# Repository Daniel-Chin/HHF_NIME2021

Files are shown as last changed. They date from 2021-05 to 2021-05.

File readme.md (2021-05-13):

# Hyper-hybrid flute, for NIME 2021
This is a snapshot of the HHF repository taken for NIME 2021. The main repository is at https://github.com/Daniel-Chin/HHF.  

- It does not incorporate the regression results, so everything is still linear;  
- and, there is a live camera capture feature for demo recording.  

This readme presents a short tutorial on how to run the demo on your computer. 

## Contact me
If it is confusing, please send feedback to me or open an issue. If you need further assistance, feel free to contact me via email.  

## How to run
### Download Processing 3
You need Processing 3 to run the software interface.  
Official site: https://processing.org/  
Download page: https://processing.org/download/  

(For those who do not want to install anything: on Windows, Processing 3 is a standalone exe.)  

Then, use Processing 3 to open file `./proc/proc.pde`. Press the play button to run.  

### Connect a MIDI output
The demo outputs MIDI messages. To hear sounds, you need to connect the demo with either a software synthesizer or a physical synthesizer.  

If you do not have any synthesizers available, Windows comes with a "Microsoft GS Wavetable Synth" that also works.  

To configure the MIDI output, edit `./midi.pde`. In that file, search for `myBus = new MidiBus`. Change the device name to your device. To see a list of detected MIDI devices, run the Processing sketch and take a look at the log output. The log output is below the source code editor.  

## Parameters
Program parameters can be found at the top of `proc.pde` and `network.pde`.  

### Keyboard-and-mouse / touchscreen demo
If you want to run the keyboard-and-mouse demo, simply make sure that `DEBUGGING_NO_ARDUINO` is set to `true` on the top of `proc.pde`.  

An arguably better experience is achieved on a touchscreen. To use the touchscreen mode, make sure that `TOUCH_SCREEN` is set to `true` on the top of `proc.pde`.  

### With-hardware demo
If you want to run the demo with our hardware, make sure that `DEBUGGING_NO_ARDUINO` is set to `false` on the top of `proc.pde`.  

Then, refer to the next section, "Hardware fabrication". 

Then, you need to setup the Bluetooth connection as a Serial port on your OS. You may refer to tutorials on "HC05 with Arduino".  

To configure the HC-05 Bluetooth module, use our helper sketch at `./ardu/setupBluetooth/setupBluetooth.ino`. 

Finally, upload `./ardu/ardu.ino` to the Arduino. 

## Hardware fabrication
### You will need
- 3D printing. 
- A six-hole recorder. 
- An Arduino Nano. 
- An HC05/HC06 Bluetooth module. 
- A BMP085 sensor. 
- Some moisture absorbers. (We just took some from packaged food.)
- A 5V battery. 
- Some bronze tape. 
- Jumper cables. 
- Optionally, 3mm-diameter nuts and bolts. 

### General guidelines
- Put bronze tape onto the recorder holes as capacitive sensors. Connect them to Arduino pin 7, 6, 5, 4, 3, 2. 
- Bluetooth Serial pins to Arduino pin 10 for RX, 11 for TX. Notice that you may need to drop the voltage to 3.3V in order to not overload the HC05. However, there is a Chinese HC06 variant that officially supports 5V. 
- Make the sensorBox. 3D models are at `./3d_models/`. I recommend to *only add support that touches buildplate*. A 3mm nut and bolt can be used to secure the sensor in the sensorBox. Add moisture absorbers above the grates. Seal the sensorBox air-tight with tape. `boxRing.stl` and `ringRail.stl` are optional parts that secure the sensorBox in the mouthpiece.  
- Connect the sensorBox sensor data pins to SDA and SCL on your Arduino.  
- Use the battery to power the Arduino.  

Again, if you have questions about any of the above steps, please refer to the "contact me" section above.

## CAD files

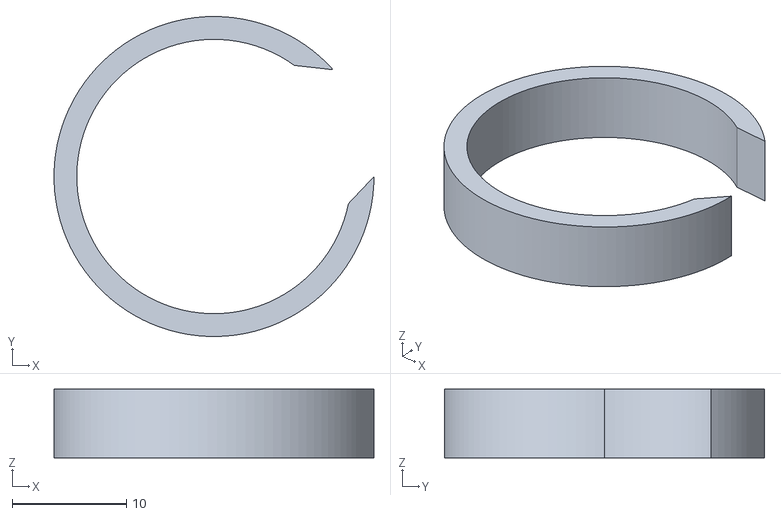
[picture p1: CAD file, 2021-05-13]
3d_models/boxRing.stl
28.0 x 28.0 x 6.00

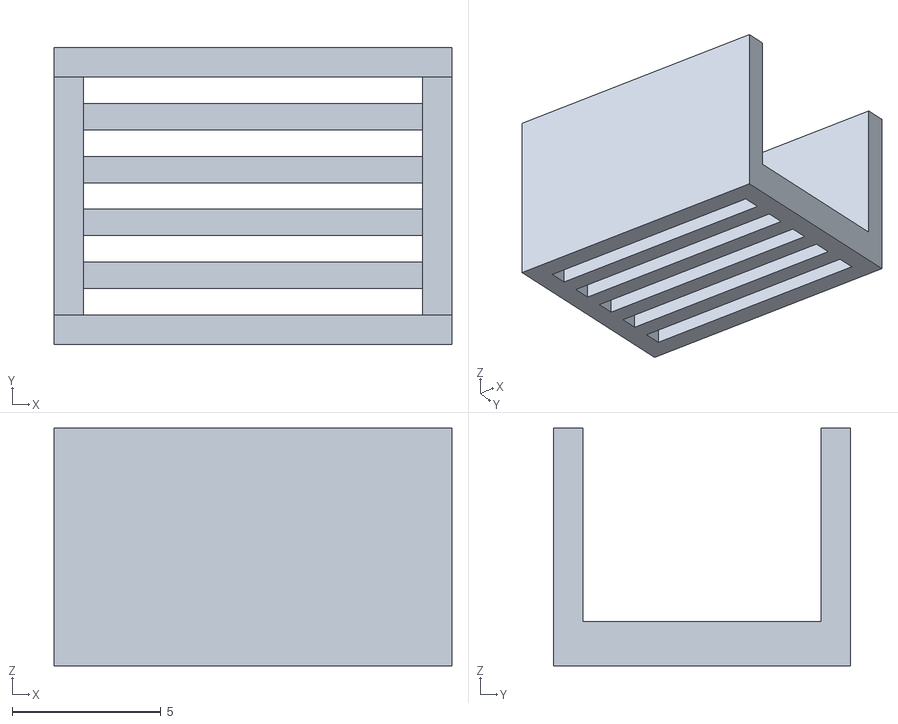
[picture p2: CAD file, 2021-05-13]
3d_models/airSensorBox_grate.stl
13.4 x 10.00 x 8.00

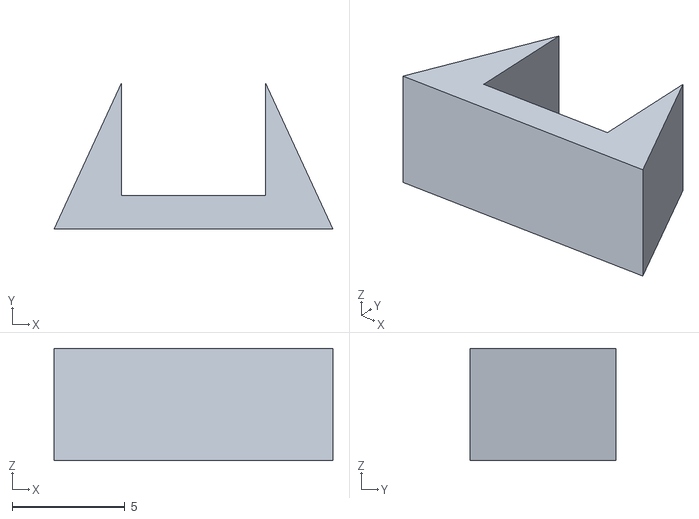
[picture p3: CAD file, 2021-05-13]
3d_models/ringRail.stl
12.4 x 6.50 x 5.00

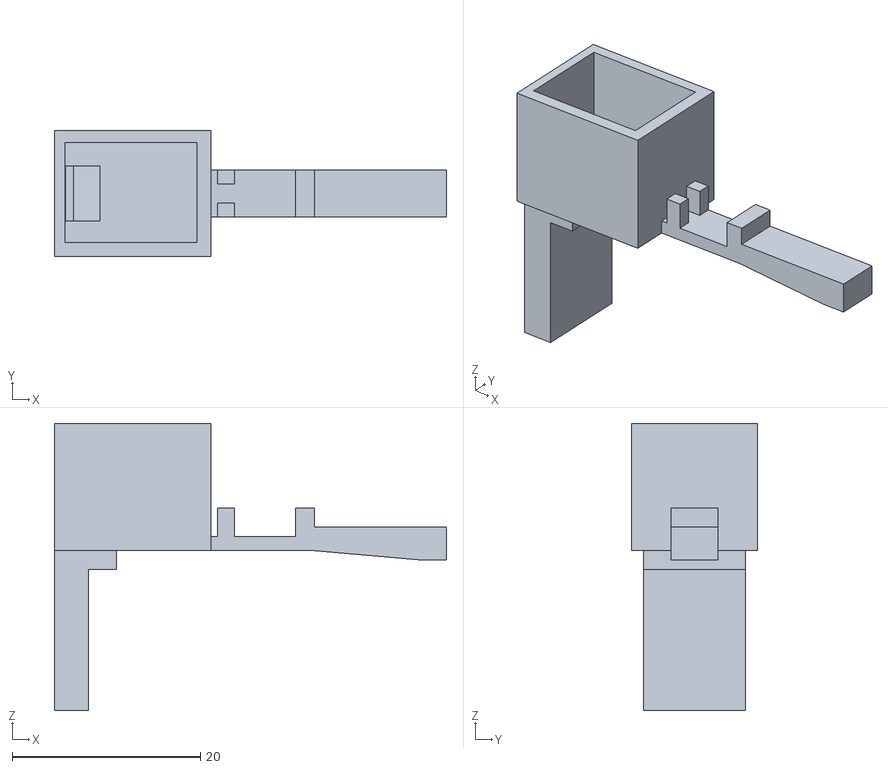
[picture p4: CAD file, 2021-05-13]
3d_models/airSensorBox_muter.stl
41.6 x 13.4 x 30.5

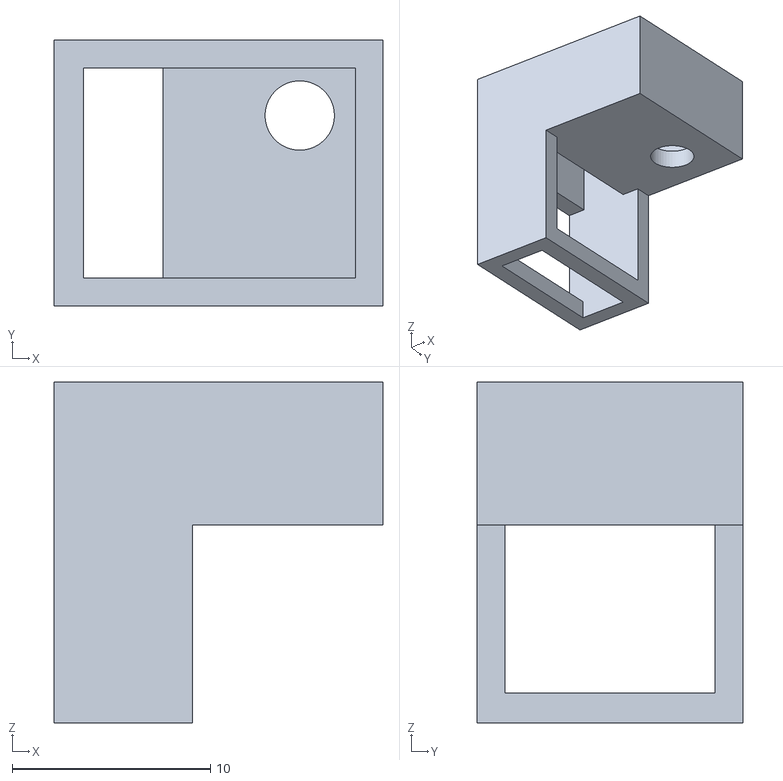
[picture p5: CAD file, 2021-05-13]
3d_models/airSensorBox_adaptor.stl
16.6 x 13.4 x 17.2

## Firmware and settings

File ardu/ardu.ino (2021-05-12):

#include <Wire.h>
#include <Adafruit_PWMServoDriver.h>
#include <SoftwareSerial.h>
#include <Adafruit_BMP085.h>

#define N_SERVOS 6
const int SERVO_PINS[N_SERVOS] = {10,11,12,13,14,15};
const int CAPACITIVE_PINS[N_SERVOS] = {7,6,5,4,3,2};
#define PEDAL_PIN 12
#define INIT_MID 95
#define DEFAULT_CAPACITIVE_THRESHOLD 2

#define MINPULSE 150 // This is the 'minimum' pulse length count (out of 4096)
#define MAXPULSE 600 // This is the 'maximum' pulse length count (out of 4096)
#define SERVO_FREQ 50 // Analog servos run at ~50 Hz updates
#define OSC_FREQ 24890000 // Specific to each PCA 9685 board

#define ROUND_ROBIN_PACKET_MAX_SIZE 127 // one-byte length indicator maximum 127 on serial

Adafruit_PWMServoDriver pwm;
Adafruit_BMP085 bmp;
SoftwareSerial blueSerial(10, 11); // RX, TX
bool _abort = false;

// For detach
int detach_slow = 5;
int last_degree[N_SERVOS] = {0};
int detach_target_degree[N_SERVOS] = {0};
int last_detach_millis;
int capacitive_threshold = DEFAULT_CAPACITIVE_THRESHOLD;
#define ATMOS_OFFSET 36000
int atmos_pressure = -1;
int measure_atmos_state = 20;
long measure_atmos_tmp = 0;
int measure_atmos_times = 0;

// For Serial communication
#define BUFF_LEN_S 4
#define BUFF_LEN_D 5
#define BUFF_LEN_C 1
#define BUFF_LEN_R 6
#define LONGEST_COMMAND 6  // max(BUFF_LEN_ S D R)
char command_buffer[LONGEST_COMMAND] = {' '};
char header = NULL;
int n_char_expect;
int n_char_got;
bool hand_shaked = false;

// For capacitive diffing
bool last_capacitive[N_SERVOS] = {false};

// For pedal diffing
bool last_pedal = false;

void setup() {
  // pwm = Adafruit_PWMServoDriver()
  // pwm.begin();
  // pwm.setOscillatorFrequency(OSC_FREQ);
  // pwm.setPWMFreq(SERVO_FREQ);

  // for (int i = 0; i < N_SERVOS; i++) {
  //   setServo(i, INIT_MID);
  //   last_degree[i] = INIT_MID; // in case you relax() before sending any attach command
  // }

  // pinMode(PEDAL_PIN, INPUT);
  blueSerial.begin(9600);
  String expecting = "hi arduino";
  int len = expecting.length();
  for (int i = 0; i < len; i++) {
    if (readOne() != expecting[i]) {
      _abort = true;
      fatalError("Handshake failed! ");
      return;
    }
  }
  blueSerial.print("hi processing");
  hand_shaked = true;
  
  if (! bmp.begin()) {
    fatalError("Could not find a valid BMP085 sensor, check wiring!");
    return;
  }

  last_detach_millis = millis();
}

char readOne() {    // blocking
  int recved = -1;
  while (recved == -1) {
    recved = blueSerial.read();
  }
  return (char) recved;
}

int heart_beat_count = 0;
void heartBeat() { // for debug
    heart_beat_count ++;
    if (heart_beat_count == 10000) {
        roundRobin_println("HEARTBEAT");
    }
    if (heart_beat_count == 30000) {
        heart_beat_count = 0;
        roundRobin_println("  HEARTBEAT");
    }
}

void loop() {
  if (_abort) {
    roundRobin_loop();
    delay(1);
    return;
  }
  roundRobin_loop();
  // heartBeat();
  // handleDetach();
  if (roundRobin_available() > 0) {
    mySerialEvent();
  }
  relayCapacitive();
  // relayPedal();
  relayPressure();
}

void mySerialEvent() {
  if (! hand_shaked) return;
  char recved;
  while (roundRobin_available()) {
    recved = roundRobin_read();
    if (header == NULL) {
      header = recved;
      n_char_got = 0;
      if (header == '\r') {
        n_char_expect = BUFF_LEN_R;
      } else if (header == 'S') {
        n_char_expect = BUFF_LEN_S;
      } else if (header == 'D') {
        n_char_expect = BUFF_LEN_D;
      } else if (header == 'C') {
        n_char_expect = BUFF_LEN_C;
      } else {
        fatalError("Unknown header: chr(" + String(int(header)) + ')');
        return;
      }
    } else {
      command_buffer[n_char_got] = recved;
      n_char_got ++;
      if (n_char_got == n_char_expect) {
        handleCommand();
        header = NULL;
      }
    }
  }
}

void handleCommand() {
  if (header == '\r') {
    String str_command = String(command_buffer).substring(0, 6);  // Stupid \x00 problem
    if (str_command.equals("ABORT_")) {
      _abort = true;
      return;
    } else {
      fatalError("Unknown command starting with \\r: ");
      roundRobin_println(str_command);
      return;
    }
  } else if (header == 'S' || header == 'D') {
    int servo_ID = int(command_buffer[1]) - int('2');
    if (command_buffer[0] == 'R') {
      servo_ID += 3;
    }
    if (servo_ID >= N_SERVOS || servo_ID < 0) {
      fatalError("Invalid servo ID: ");
      roundRobin_write(command_buffer[0]);
      roundRobin_write(command_buffer[1]);
      return;
    }
    int degree = decodeDegree(command_buffer[2], command_buffer[3]);
    if (isDegreeIllegal(degree)) {
      return;
    }
    if (header == 'S') {
      attach(servo_ID, degree);
    } else if (header == 'D') {
      detach_slow = decodeDigit(command_buffer[4]);
      detach(servo_ID, degree);
    }
  } else if (header == 'C') {
    capacitive_threshold = (int) command_buffer[0];
  }
}

bool isDegreeIllegal(int degree) {
  if (degree > 180 || degree < 0) {
    fatalError("Invalid degree: ");
    roundRobin_println(String(degree));
    return true;
  }
  return false;
}

void fatalError(String msg) {
  delay(100); // avoid two-way serial collision
  roundRobin_println("ERRArduino fatal Error: " + msg);
  _abort = true;
}

int decodeDigit(char x) {
  return (int) x - (int) '0';
}

int decodeDegree(char a, char b) {
  return 127 * (int(a) - 1) + int(b) - 1;
}

void detach(int servo_ID, int degree) {
  detach_target_degree[servo_ID] = degree;
}

void attach(int servo_ID, int degree) {
  setServo(servo_ID, degree);
  last_degree[servo_ID] = degree;
  detach_target_degree[servo_ID] = NULL;
}

void handleDetach() {
  while ((millis() + 1000 - last_detach_millis) % 1000 >= detach_slow) {
    last_detach_millis += detach_slow;
    last_detach_millis %= 1000;
    for (int i = 0; i < N_SERVOS; i++) {
      if (detach_target_degree[i] != NULL) {
        if (detach_target_degree[i] > last_degree[i]) {
          last_degree[i] ++;
        } else {
          last_degree[i] --;
        }
        setServo(i, last_degree[i]);
        if (last_degree[i] == detach_target_degree[i]) {
          detach_target_degree[i] = NULL;
        }
      }
    }
  }
}

uint8_t readCapacitivePin(int pinToMeasure) {
  volatile uint8_t* port;
  volatile uint8_t* ddr;
  volatile uint8_t* pin;
  byte bitmask;
  port = portOutputRegister(digitalPinToPort(pinToMeasure));
  ddr = portModeRegister(digitalPinToPort(pinToMeasure));
  bitmask = digitalPinToBitMask(pinToMeasure);
  pin = portInputRegister(digitalPinToPort(pinToMeasure));
  *port &= ~(bitmask);
  *ddr  |= bitmask;
  delay(1);
  uint8_t SREG_old = SREG; //back up the AVR Status Register
  noInterrupts();
  *ddr &= ~(bitmask);
  *port |= bitmask;
  uint8_t cycles = 17;
  if (*pin & bitmask) {
    cycles =  0;
  } else if (*pin & bitmask) {
    cycles =  1;
  } else if (*pin & bitmask) {
    cycles =  2;
  } else if (*pin & bitmask) {
    cycles =  3;
  } else if (*pin & bitmask) {
    cycles =  4;
  } else if (*pin & bitmask) {
    cycles =  5;
  } else if (*pin & bitmask) {
    cycles =  6;
  } else if (*pin & bitmask) {
    cycles =  7;
  } else if (*pin & bitmask) {
    cycles =  8;
  } else if (*pin & bitmask) {
    cycles =  9;
  } else if (*pin & bitmask) {
    cycles = 10;
  } else if (*pin & bitmask) {
    cycles = 11;
  } else if (*pin & bitmask) {
    cycles = 12;
  } else if (*pin & bitmask) {
    cycles = 13;
  } else if (*pin & bitmask) {
    cycles = 14;
  } else if (*pin & bitmask) {
    cycles = 15;
  } else if (*pin & bitmask) {
    cycles = 16;
  }
  SREG = SREG_old;
  *port &= ~(bitmask);
  *ddr  |= bitmask;
  return cycles;
}

void relayCapacitive() {
  for (int i = 0; i < N_SERVOS; i ++) {
    uint8_t reading = readCapacitivePin(CAPACITIVE_PINS[i]);
    bool is_finger_down = reading >= capacitive_threshold;
    if (is_finger_down != last_capacitive[i]) {
      last_capacitive[i] = is_finger_down;
      roundRobin_write('F');
      roundRobin_write((char) ((int)'0' + i));
      if (is_finger_down) {
        roundRobin_write('_');
      } else {
        roundRobin_write('^');
      }
    }
  }
}

void relayPedal() {
  bool now_pedal = digitalRead(PEDAL_PIN);
  if (now_pedal != last_pedal) {
    last_pedal = now_pedal;
    roundRobin_write('P');
    if (now_pedal) {
      roundRobin_write('_');
    } else {
      roundRobin_write('^');
    }
    roundRobin_write(';');
  }
}

void setServo(int id, int angle) {
  pwm.setPWM(SERVO_PINS[id], 0, map(angle, 0, 180, MINPULSE, MAXPULSE));
}

void sendDebugMsg(String msg) {
  roundRobin_write('D');
  roundRobin_print(msg.substring(0, 2));
}

// Round Robin
String round_robin_in_queue = "";
String round_robin_out_queue = "";
int round_robin_my_turn = false;
int round_robin_recv_state = -1;

void roundRobin_loop() {
  if (round_robin_my_turn) {
    int packet_size = min(round_robin_out_queue.length(), ROUND_ROBIN_PACKET_MAX_SIZE);
    blueSerial.write((char) packet_size);
    if (packet_size > 0) {
      blueSerial.print(round_robin_out_queue.substring(0, packet_size));
      round_robin_out_queue = round_robin_out_queue.substring(packet_size);
    }
    round_robin_my_turn = false;
    round_robin_recv_state = -1;
  } else if (! _abort) {
    while (blueSerial.available() > 0) {
      if (round_robin_recv_state == -1) {
        round_robin_recv_state = blueSerial.read();
      } else {
        // rr_state > 0
        round_robin_in_queue += (char) blueSerial.read();
        // This leads to memory fragmentation quickly. 
        // Too bad.
        round_robin_recv_state -= 1;
      }
      if (round_robin_recv_state == 0) {
        round_robin_my_turn = true;
        break;
      }
    }
  }  
}

int roundRobin_available() {
  return round_robin_in_queue.length();
}

char roundRobin_read() {
  char tmp = round_robin_in_queue.charAt(0);
  round_robin_in_queue = round_robin_in_queue.substring(1);
  return tmp;
}

void roundRobin_write(char x) {
  round_robin_out_queue += x;
}

void roundRobin_print(String x) {
  round_robin_out_queue += x;
}

void roundRobin_println(String x) {
  roundRobin_print(x);
  roundRobin_write('\n');
}

void relayPressure() {
  int p = bmp.readPressure() - ATMOS_OFFSET;
  if (measure_atmos_state >= 0) {
    measure_atmos_tmp += p;
    measure_atmos_times ++;
    if (measure_atmos_state == 0) {
      atmos_pressure = measure_atmos_tmp / measure_atmos_times;
      // roundRobin_print("E");
      // roundRobin_print(String(atmos_pressure));
    }
    measure_atmos_state --;
  } else {
    p -= atmos_pressure;
    p = max(0, p);
    roundRobin_write('B');
    roundRobin_print(encodePrintable(p));
  }
}

String encodePrintable(int x) {
  int residual = x % 95;
  int high = (x - residual) / 95;
  high = min(94, high);
  char buffer[3] = { 0 };   // \x00 termination
  buffer[0] = (char)(high + 32);
  buffer[1] = (char)(residual + 32);
  String result = buffer;
  return result;
}

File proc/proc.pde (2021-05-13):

import java.util.Arrays;
import processing.serial.*;
import processing.video.*;

final static boolean DEBUGGING_NO_ARDUINO = true;
// true: a mouse-based demo. false: connects to the hardware. 
final static int COM = 3;
// Port ID. In console log, look for the bluetooth port. 
final static boolean TOUCH_SCREEN = false;
final static float FLUTE_BEND_MAX = .3;
// pitch bend coefficient. 
final static int CAPACITIVE_THRESHOLD = 3;
// increase on humid days. 
final static int LOW_PASS = 75;
// low pass filter, milliseconds. 
final static boolean MIDI_advanced_expression = false;
// whether MIDI channel 7 or 11 is used. 
final static int MAX_VELOCITY = 600;
// if using the mouse-based demo, the top of the screen corresponds to MAX_VELOCITY
final static float CURSOR_SIZE = 1f;
final static int TRANSPOSE_OCTAVES = 5;

final static String TITLE = "The Hyper-hybrid Flute";
final static int ROUND_ROBIN_PACKET_MAX_SIZE = 127;  // one-byte length indicator maximum 127 on serial
final static int TRANSPOSE = TRANSPOSE_OCTAVES * 12;

final static int CAM_WIDTH = 650;
final static int CAM_Y = 0;

int _WIDTH;
Capture cam;
Port port;
boolean abort = false;
String abort_msg = "ABORT";
SceneHandshake sceneHandshake = null;

void setup() {
  size(1366, 768);
  // fullScreen();
  _WIDTH = width - CAM_WIDTH;
  fill(255);
  textAlign(CENTER);
  textSize(36);
  noStroke();
  gui = new GUI();
  if (! DEBUGGING_NO_ARDUINO) {
    sceneHandshake = new SceneHandshake();
  }
  String[] cameras = Capture.list();
  if (cameras.length == 0) {
    println("There are no cameras available for capture.");
    cam = new Capture(this, "pipeline:autovideosrc");
    cam.start();
  } else {
    println("Available cameras:");
    for (int i = 0; i < cameras.length; i++) {
      println(cameras[i]);
    }
    cam = new Capture(this, cameras[0]);
    cam.start();     
  }      
}

class Port {
  // logs communications
  // fake a dummy interface when DEBUGGING_NO_ARDUINO is false
  // Do the Round Robin for bluetooth
  Serial serial;
  PrintWriter sendLogger;
  PrintWriter recvLogger;
  String outQueue = "";
  String inQueue = "";
  boolean round_robin_my_turn = true;
  int round_robin_recv_state = -1;

  void initLoggers() {
    sendLogger = createWriter("Serial_proc_ardu.log");
    recvLogger = createWriter("Serial_ardu_proc.log");
  }
  public Port(Serial serial) {
    this.serial = serial;
    initLoggers();
  }
  public Port(String s) {
    assert s.equals("fake");
    initLoggers();
  }
  void loop() {
    if (DEBUGGING_NO_ARDUINO) return;
    if (round_robin_my_turn) {
      int packet_size = min(outQueue.length(), ROUND_ROBIN_PACKET_MAX_SIZE);
      serial.write(packet_size);
      if (packet_size > 0) {
        serial.write(outQueue.substring(0, packet_size));
        outQueue = outQueue.substring(packet_size);
      }
      round_robin_my_turn = false;
      round_robin_recv_state = -1;
    } else {
      while (serial.available() > 0) {
        if (round_robin_recv_state == -1) {
          round_robin_recv_state = serial.read();
        } else {
          // rr_state > 0
          inQueue += serial.readChar();
          round_robin_recv_state -= 1;
        }
        if (round_robin_recv_state == 0) {
          round_robin_my_turn = true;
          break;
        }
      }
    }
  }
  void write(String s, boolean log_line_break) {
    if (! DEBUGGING_NO_ARDUINO) {
      outQueue += s;
    }
    sendLogger.print(s);
    if (log_line_break) {
      sendLogger.println();
    }
  }
  void write(String s) {
    this.write(s, false);
  }
  char read() {
    if (! DEBUGGING_NO_ARDUINO) {
      char recved = inQueue.charAt(0);
      inQueue = inQueue.substring(1);
      recvLogger.print(recved);
      return recved;
    } else return '_';
  }
  int available() {
    if (! DEBUGGING_NO_ARDUINO) {
      return inQueue.length();
    } else return 0;
  }
  char serial_readOne() {  // blocks until got one char
    while (serial.available() == 0) {
      delay(1);
    }
    return (char) serial.read();
  }
  String readAll() {
    String tmp = inQueue;
    inQueue = "";
    recvLogger.print(tmp);
    return tmp;
  }
  void close() {
    sendLogger.flush();
    sendLogger.close();
    recvLogger.flush();
    recvLogger.close();
  }
}

void draw() {
  if (abort) {
    background(0);
    fill(255);
    textSize(72);
    textAlign(CENTER, CENTER);
    text(abort_msg, 0, 0, width, height);
    return;
  }
  if (arduino == null && sceneHandshake != null) {
    sceneHandshake.draw();
    return;
  }
  if (arduino != null) {
    if (port != null) {
      port.loop();
    }
    arduino.loop();
  }
  network.loop();
  pushMatrix();
    translate(CAM_WIDTH, 0);
    gui.loop();
  popMatrix();
  if (cam.available() == true) {
    cam.read();
  }
  // image(cam, 0, 0);
  set(0, CAM_Y, cam);
}

PApplet getThis() {
  return this;
}

void keyPressed() {
  if (key == ESC) {
    stop();
  }
}

void stop() {
  println("Application terminates.");
  midiOut.clear();
  if (port != null) {
    port.sendLogger.flush();
    port.sendLogger.close();
    port.recvLogger.flush();
    port.recvLogger.close();
  }
  super.stop();
}
